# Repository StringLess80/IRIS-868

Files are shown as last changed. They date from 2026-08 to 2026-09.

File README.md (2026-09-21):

<div align="center">

# 📡 IRIS-868

**Custom embedded RF platform for the 868 MHz ISM band**

IRIS-868 is a custom embedded RF platform based on the STM32F303RET6 microcontroller and an Ebyte E22-900M22S (Semtech SX1262) sub-GHz LoRa module, designed for 868 MHz ISM-band wireless communication and data logging.

<br/>














<br/>

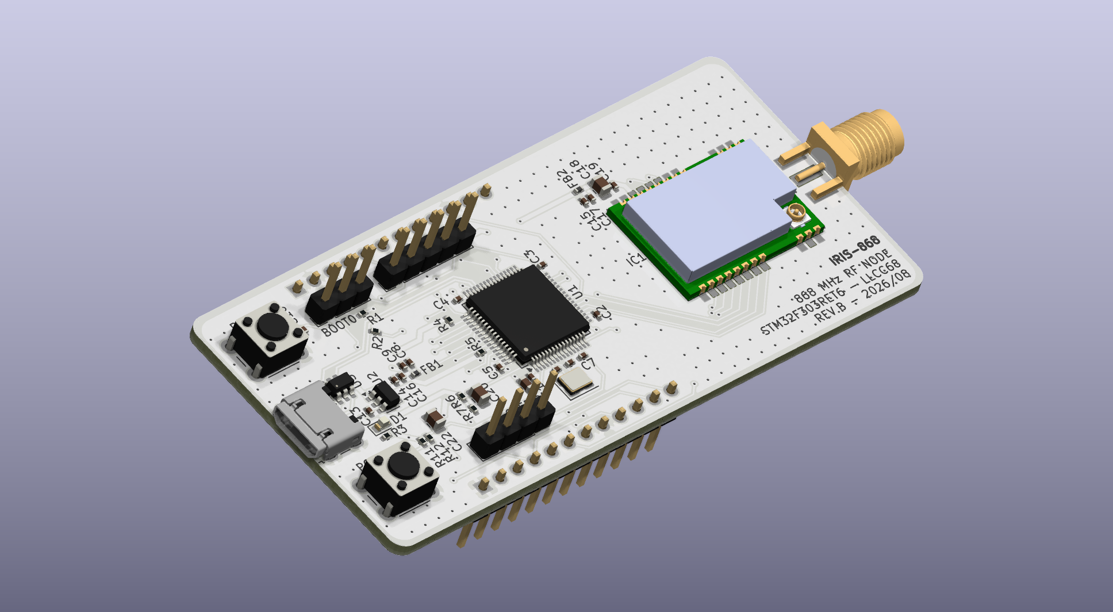
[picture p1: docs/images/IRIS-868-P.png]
IRIS-868


</div>

---

## ⚡ At a glance

|  |  |
|---|---|
| 🧠 **MCU** | STM32F303RET6 · Cortex-M4F @ 72 MHz · 512 KB flash · 64 + 16 KB RAM |
| 📻 **Radio** | Ebyte E22-900M22S · SX1262 · +22 dBm · LoRa / (G)FSK |
| 💾 **Storage** | Winbond W25Q128JV · 128 Mbit (16 MiB) SPI NOR flash for data logging |
| 🔌 **Power** | USB micro-B → AP2112K-3.3 LDO, filtered analog and RF rails, VBUS voltage monitoring on the ADC |
| 🧩 **Expansion** | 2 × 12-pin edge headers · I²C header for 128×64 OLED · 5-pin SWD with NRST · BOOT0 jumper · user button |
| 📐 **Board** | 2-layer FR4 · 78.8 × 36.6 mm · white mask, black silk · components on both sides |
| 🛠️ **Tooling** | KiCad 9, project-local libraries, no global config needed |

> [!WARNING]
> **Revision B is design-complete but has not been bring-up tested.** Fabrication files are released as-is. No firmware is included in this repository yet. See [Known limitations](#-known-limitations) before ordering.

## 📑 Table of contents

- [What's new in revision B](#-whats-new-in-revision-b)
- [Gallery](#%EF%B8%8F-gallery)
- [System architecture](#%EF%B8%8F-system-architecture)
- [Repository layout](#-repository-layout)
- [Hardware overview](#-hardware-overview)
- [Pin assignment](#-pin-assignment)
- [Board specification](#-board-specification)
- [Bill of materials](#-bill-of-materials)
- [Getting started](#-getting-started)
- [Known limitations](#-known-limitations)

## 🆕 What's new in revision B

| Area | Revision A | Revision B |
|---|---|---|
| **Expansion** | Most GPIOs unrouted | Two 1×12 edge headers (J5, J7) bring out power, reset, BOOT0, USART1 and 13 GPIOs |
| **Debug** | 4-pin SWD, no NRST | 5-pin SWD **with NRST** — "connect under reset" now works |
| **Storage** | — | 16 MiB W25Q128JV SPI flash on SPI3 (bottom side) |
| **User input** | Reset button only | Additional user button on **PC13** with RC debounce |
| **Monitoring** | — | VBUS divider (47 kΩ / 15 kΩ) on **PC0** for USB voltage measurement |
| **USB** | D+ pull-up fixed to +3.3 V | D+ pull-up driven by **PB8** — firmware-controlled attach/detach |
| **Radio** | E220-900M22S (LLCC68) | E22-900M22S (SX1262), same pinout and pin assignment |
| **Board** | 74.2 × 32.0 mm, single-sided assembly | 78.8 × 36.6 mm, bottom-side SMD parts and headers |

## 🖼️ Gallery

<div align="center">

| Front | Back |
|:---:|:---:|
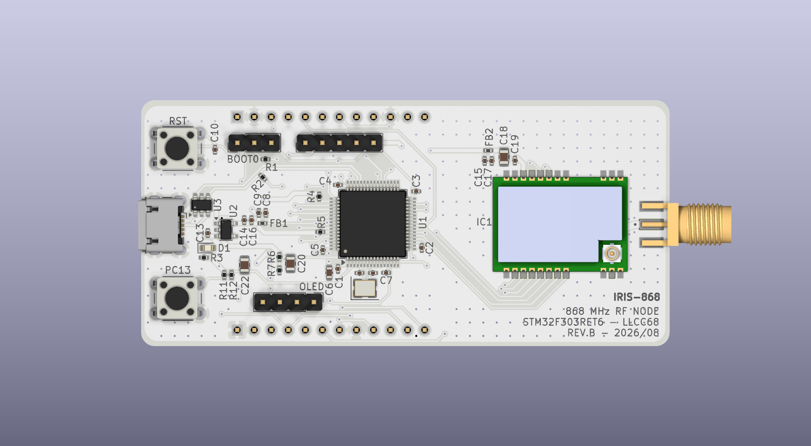
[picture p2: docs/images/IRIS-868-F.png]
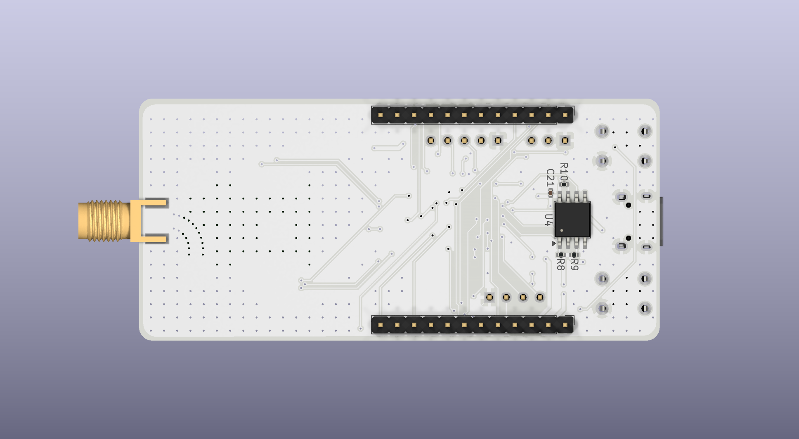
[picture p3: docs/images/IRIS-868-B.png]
|  |  |

</div>

📄 Full schematic: [`docs/schematics/IRIS-868.pdf`](docs/schematics/IRIS-868.pdf)

## 🏗️ System architecture

```mermaid
flowchart LR
    USB["USB micro-B<br/>J2"] -->|VBUS 5 V| LDO["AP2112K-3.3<br/>600 mA LDO"]
    USB -.->|"D+ / D-"| ESD["USBLC6-2SC6<br/>ESD"]
    ESD -.-> MCU
    USB -->|"VBUS ÷ 4.13"| VMON["V_MON<br/>PC0 / ADC"]
    VMON --> MCU

    LDO --> RAIL(("3.3 V"))
    RAIL -->|"FB1 120 Ω"| VDDA["+3.3VA"]
    RAIL -->|"FB2 120 Ω"| VRF["VRF"]
    RAIL --> MCU
    VDDA --> MCU
    VRF --> MOD

    MCU["STM32F303RET6<br/>Cortex-M4F @ 72 MHz"]
    MCU <-->|"SPI1 · NSS · BUSY · DIO1 · NRST"| MOD["E22-900M22S<br/>SX1262 · +22 dBm"]
    MCU -->|"RXEN / TXEN"| MOD
    MOD -->|ANT| SMA["SMA edge<br/>J6"]

    MCU <-->|"SPI3 · CS"| FLASH["W25Q128JV<br/>16 MiB flash"]
    MCU <-->|"I²C1"| OLED["128×64 OLED<br/>header"]
    MCU <-->|"SWD + NRST"| DBG["ST-Link<br/>J3"]
    MCU <-->|"GPIO · USART1"| HDR["Edge headers<br/>J5 / J7"]
    BTN["User button<br/>PC13"] --> MCU
    MCU -.->|BOOT0| JMP["Boot jumper"]

    style MCU fill:#03234B,color:#fff
    style MOD fill:#2ea44f,color:#fff
    style FLASH fill:#8e44ad,color:#fff
    style RAIL fill:#f39c12,color:#fff
```

## 📁 Repository layout

```
IRIS-868/
├── hardware/
│   ├── kicad/                 KiCad 9 project (schematic, PCB, design rules)
│   │   └── libs/              Project-local symbols, footprints, 3D models
│   └── gerbers/rev.B/         Gerber X2 + Excellon drill files
└── docs/
    ├── schematics/            Schematic PDF
    ├── images/                Board renders
    └── datasheets/            Component reference documents
```

The schematic is hierarchical: the root sheet (`IRIS-868.kicad_sch`) holds the MCU, crystal, reset, buttons, VBUS monitor, flash and headers, with sub-sheets for power and USB (`pwr.kicad_sch`), the radio (`rf.kicad_sch`) and connectors (`interfaces.kicad_sch`).

## 🔧 Hardware overview

### Power

USB VBUS feeds an **AP2112K-3.3** LDO (SOT-23-5, 600 mA) that generates the single 3.3 V system rail. Three domains branch from it:

| Rail | Source | Decoupling | Purpose |
|---|---|---|---|
| `+3.3V` | LDO output | 10 µF + 7 × 100 nF + 2 × 1 µF | MCU digital, I/O, flash, headers |
| `+3.3VA` | via FB1 (120 Ω ferrite) | 1 µF + 10 nF | STM32 VDDA / analog reference |
| `VRF` | via FB2 (120 Ω ferrite) | 22 µF + 1 µF + 2 × 100 nF | RF module supply |

The ferrite beads isolate the analog and RF domains from digital switching noise on the main rail. The 22 µF bulk capacitor on `VRF` supplies the current burst drawn by the module during transmission.

VBUS and +3.3 V are both available on header J5, so the board can supply a small carrier or add-on board.

### VBUS monitoring

A 47 kΩ / 15 kΩ divider (R6 / R7) scales VBUS onto `V_MON` (**PC0**, ADC12_IN6), filtered by C20 (100 nF). The divider ratio is 15 / 62, so 5.0 V on VBUS reads as about 1.21 V, and firmware recovers VBUS as `V_MON × 4.133`. The divider draws roughly 80 µA from VBUS, and its ~11 kΩ source impedance combined with C20 gives a stable input for the ADC sample-and-hold.

### RF chain

The E22-900M22S connects to the MCU over SPI1 plus four control lines. `RXEN` and `TXEN` drive the module's internal RF switch and must be managed by firmware around every transmit/receive transition. The antenna net (`ANT`) runs from the module's stamp-hole RF pad to the SMA edge connector as a short (≈ 4.6 mm), 1.0 mm-wide ground-referenced coplanar trace on F.Cu; a project-specific design rule enforces a 0.15 mm gap to the surrounding copper pour along this net.

### Data-logging flash

A **Winbond W25Q128JVSIQ** (SOIC-8, 208 mil) on the bottom side provides 16 MiB of non-volatile storage on **SPI3** (PC10 / PC11 / PC12) with chip select on **PD2**. The CS line has a 10 kΩ pull-up (R8) so the flash stays deselected while the MCU is in reset. `/WP` and `/HOLD` are tied high through R9 and R10, so the device operates in standard single-bit SPI mode; dual/quad I/O is not available on this revision. C21 decouples the flash locally.

### User input and reset

| Button | Net | Circuit |
|---|---|---|
| **RST** | NRST (pin 7) | Pulls NRST low, 100 nF (C10) on the line. NRST is also on the SWD header and J5 |
| **PC13** | PC13 (pin 2) | Active-low. 10 kΩ pull-up (R11), 10 kΩ series (R12), 100 nF (C22) to GND — about 1 ms fall / 2 ms rise debounce |

### USB

The USB D+ 1.5 kΩ pull-up (R2) is connected to **PB8** rather than to +3.3 V. Firmware must drive PB8 high to signal device attach to the host, and can drive it low to force a clean disconnect/re-enumeration without unplugging the cable. See [Known limitations](#-known-limitations) for the effect on the ROM DFU bootloader.

### Interfaces

| Connector | Type | Pinout |
|---|---|---|
| **J2** USB | micro-B | USB FS device on PA11/PA12, D+ pull-up switched by PB8, ESD-protected |
| **J3** SWD | 1×5 @ 2.54 mm | `GND` · `NRST` · `SWCLK` · `SWDIO` · `+3.3V` |
| **BOOT0** | 1×3 @ 2.54 mm | `GND` · `BOOT0` · `+3.3V` — jumper 1–2 = flash, 2–3 = bootloader |
| **OLED** | 1×4 @ 2.54 mm | `GND` · `+3.3V` · `SCL` · `SDA` (1.5 kΩ pull-ups on board) |
| **J5** | 1×12 @ 2.54 mm, bottom-mounted | Power, reset, BOOT0, USART1, GPIO — see below |
| **J7** | 1×12 @ 2.54 mm, bottom-mounted | GPIO — see below |
| **J6** SMA | edge-mount | Antenna |

### Edge headers

J5 and J7 run along the long edges of the board with a row-to-row spacing of 31.75 mm (1.25 in). The header bodies are mounted on the bottom side, so the board can be plugged into a carrier with the components facing up. Pin 1 of each header is at the USB end.

| Pin | **J5** | **J7** |
|:---:|---|---|
| 1 | `GND` | `PB9` |
| 2 | `+3.3V` | `GND` |
| 3 | `VBUS` (5 V) | `PB0` |
| 4 | `NRST` | `PB1` |
| 5 | `BOOT0` | `PC4` |
| 6 | `PA9` (USART1_TX) | `PC5` |
| 7 | `PA10` (USART1_RX) | `PC6` |
| 8 | `GND` | `PC7` |
| 9 | `PB4` | `PC8` |
| 10 | `PB5` | `GND` |
| 11 | `PB6` | not connected |
| 12 | `PB8` ⚠️ USB D+ pull-up | not connected |

## 📌 Pin assignment

### STM32F303RET6 ↔ E22-900M22S

| STM32 pin | Signal | Module pin | Direction | Function |
|---|---|---|:---:|---|
| `PA5` | SPI1_SCK | 18 (SCK) | → | SPI clock |
| `PA6` | SPI1_MISO | 16 (MISO) | ← | SPI data out |
| `PA7` | SPI1_MOSI | 17 (MOSI) | → | SPI data in |
| `PA4` | NSS | 19 (NSS) | → | Chip select, active low |
| `PA3` | NRST | 15 (NRST) | → | Module reset, active low |
| `PA2` | BUSY | 14 (BUSY) | ← | Transceiver busy status |
| `PA8` | DIO1 | 13 (DIO1) | ← | Primary interrupt line |
| `PB10` | RXEN | 6 (RXEN) | → | RF switch, receive enable |
| `PB11` | TXEN | 7 (TXEN) | → | RF switch, transmit enable |

Module pin 8 (DIO2) is left unconnected in revision B.

### STM32F303RET6 ↔ W25Q128JV

| STM32 pin | Signal | Flash pin | Direction |
|---|---|---|:---:|
| `PC10` | SPI3_SCK | 6 (CLK) | → |
| `PC11` | SPI3_MISO | 2 (DO) | ← |
| `PC12` | SPI3_MOSI | 5 (DI) | → |
| `PD2` | FLASH_CS | 1 (/CS) | → |

<details>
<summary><b>Other pin assignments</b></summary>

<br/>

| STM32 pin | Function |
|---|---|
| `PA11` / `PA12` | USB D− / D+ |
| `PB8` | USB D+ pull-up control (also on J5 pin 12) |
| `PA13` / `PA14` | SWDIO / SWCLK |
| `PA15` | I²C1 SCL (AF4) |
| `PB7` | I²C1 SDA (AF4) |
| `PC0` | V_MON — VBUS voltage divider (ADC) |
| `PC13` | User button, active low |
| `PF0` / `PF1` | 16 MHz crystal (OSC_IN / OSC_OUT) |
| `NRST` (pin 7) | Reset button + 100 nF, SWD header, J5 |
| `BOOT0` (pin 60) | BOOT0 jumper via 10 kΩ, J5 (direct) |
| `PA9`, `PA10`, `PB4`–`PB6` | J5 |
| `PB0`, `PB1`, `PB9`, `PC4`–`PC8` | J7 |

The remaining GPIOs — `PA0`, `PA1`, `PB2`, `PB3`, `PB12`–`PB15`, `PC1`–`PC3`, `PC9`, `PC14`, `PC15` — are **not routed** in revision B.

</details>

## 📐 Board specification

| Parameter | Value |
|---|---|
| Dimensions | 78.8 × 36.6 mm, 2 mm corner radius |
| Layers | 2 (F.Cu / B.Cu), GND pour on both |
| Stackup | 1.6 mm FR4, 35 µm copper, εr 4.5 |
| Surface finish | HASL |
| Vias | 369 |
| Assembly | Double-sided (U4, R8–R10, C21 and header bodies on the bottom) |
| Special rules | 0.15 mm clearance on the `ANT` coplanar feedline |

## 🧾 Bill of materials

<details>
<summary><b>Full BOM — 52 components</b></summary>

<br/>

| Ref | Qty | Value | Package | Notes |
|---|:---:|---|---|---|
| U1 | 1 | STM32F303RET6 | LQFP-64 | 0.5 mm pitch |
| U2 | 1 | AP2112K-3.3 | SOT-23-5 | 600 mA LDO |
| U3 | 1 | USBLC6-2SC6 | SOT-23-6 | USB ESD protection |
| U4 | 1 | W25Q128JVSIQ | SOIC-8 5.3 × 5.3 mm | 128 Mbit SPI flash, **bottom side** |
| IC1 | 1 | E22-900M22S | Ebyte SMD module | SX1262, +22 dBm |
| Y1 | 1 | 16 MHz | 3225-4pin | ≤20 ppm recommended |
| C1–C5, C10, C16, C17, C19, C21 | 10 | 100 nF | 0402 | 16 V X7R — C21 on bottom side |
| C20, C22 | 2 | 100 nF | 0805 | 16 V X7R — V_MON filter, PC13 debounce |
| C8, C9, C14, C15 | 4 | 1 µF | 0402 | 16 V X5R/X7R |
| C13 | 1 | 1 µF | 0402 | **25 V** — sits on the 5 V VBUS rail |
| C6 | 1 | 10 µF | 0603 | 16 V X5R |
| C18 | 1 | 22 µF | 0805 | 16 V X5R, RF bulk |
| C7 | 1 | 10 nF | 0402 | 16 V X7R, VDDA filter |
| C11, C12 | 2 | 12 pF | 0402 | **50 V C0G/NP0 ±5%**, crystal load |
| R1 | 1 | 10 kΩ | 0402 | BOOT0 series |
| R2 | 1 | 1.5 kΩ | 0402 | USB D+ pull-up (to PB8) |
| R3 | 1 | 1.5 kΩ | 0402 | Power LED series |
| R4, R5 | 2 | 1.5 kΩ | 0402 | I²C pull-ups |
| R6 | 1 | 47 kΩ | 0402 | VBUS divider, top — 1% recommended |
| R7 | 1 | 15 kΩ | 0402 | VBUS divider, bottom — 1% recommended |
| R8, R9, R10 | 3 | 10 kΩ | 0402 | Flash /CS, /WP, /HOLD pull-ups, **bottom side** |
| R11, R12 | 2 | 10 kΩ | 0402 | PC13 button pull-up / series |
| FB1, FB2 | 2 | 120 Ω @ 100 MHz | 0402 | Analog / RF rail filtering |
| D1 | 1 | Red LED | 0603 | Power indicator |
| RST, PC13 | 2 | Tactile switch | 6 mm THT | 4-pin, 4.5 × 6.5 mm |
| BOOT0 | 1 | Pin header 1×3 | 2.54 mm | BOOT0 select |
| J2 | 1 | USB micro-B | Würth 629105150521 | |
| J3 | 1 | Pin header 1×5 | 2.54 mm | SWD + NRST |
| OLED | 1 | Pin header 1×4 | 2.54 mm | I²C / OLED |
| J5, J7 | 2 | Pin header 1×12 | 2.54 mm | Edge headers, **bottom side** |
| J6 | 1 | SMA edge-mount | RF Solutions CON-SMA-EDGE-S | |

</details>

> [!TIP]
> Capacitor voltage ratings account for MLCC **DC bias derating** — class II ceramics lose a large fraction of their nominal capacitance near their rated voltage, so ratings are specified at roughly 4–5× the working voltage. Don't forget to order a **2.54 mm jumper shunt** for the BOOT0 header; it isn't part of the PCB BOM.

## 🚀 Getting started

<details open>
<summary><b>1 · Fabricate the board</b></summary>

<br/>

Fabrication files for revision B are in [`hardware/gerbers/rev.B/`](hardware/gerbers/rev.B/), in Gerber X2 format with Excellon drill files. They can be uploaded directly to most fabricators.

- Process: standard 2-layer, 1.6 mm FR4, HASL or ENIG
- No controlled impedance is specified
- Revision B has SMD parts on **both sides**. If using assembly service, request double-sided assembly or have the bottom-side parts (U4, R8–R10, C21) left unpopulated and fit them by hand
- Suggested hand-assembly order: bottom-side SMD parts first, then the STM32 (drag solder, then inspect with flux and a loupe), then the remaining ICs, then passives, then the module, then through-hole parts last — edge headers J5/J7 go in from the bottom

</details>

<details>
<summary><b>2 · Open the design</b></summary>

<br/>

The project requires **KiCad 9** or later. Symbols, footprints and 3D models for the non-standard parts (E22 module, SMA edge connector) live under `hardware/kicad/libs/` and are referenced with project-relative paths, so the project opens without any global library configuration.

```bash
git clone -b v2 https://github.com/StringLess80/IRIS-868.git
cd IRIS-868
kicad hardware/kicad/IRIS-868.kicad_pro
```

</details>

<details>
<summary><b>3 · Program it</b></summary>

<br/>

**Via SWD (recommended)** — connect an ST-Link or any CMSIS-DAP probe to J3, including the NRST line. Because NRST is on the header, "connect under reset" works, so a board with firmware that disables SWD or enters low-power mode early can still be recovered from the debugger.

```bash
st-flash --reset write firmware.bin 0x08000000
```

**Via UART bootloader** — connect a 3.3 V USB-serial adapter to J5 (`PA9` = MCU TX, `PA10` = MCU RX, `GND`), move the BOOT0 jumper to pins 2–3 and reset:

```bash
stm32flash -w firmware.bin -v -g 0x0 /dev/ttyUSB0
```

**Via USB DFU** — the ROM bootloader does not drive PB8, so the D+ pull-up is inactive and the host will not see the device (see [Known limitations](#-known-limitations)). Tie J5 pin 12 (`PB8`) to J5 pin 2 (`+3.3V`) for the duration of the DFU session, move the BOOT0 jumper to pins 2–3, reset, then:

```bash
dfu-util -a 0 -s 0x08000000:leave -D firmware.bin
```

> [!CAUTION]
> Remove the PB8 link before running application firmware — if firmware drives PB8 low while it is tied to +3.3 V, the pin is shorted.

Move the jumper back to pins 1–2 and reset to run from flash.

</details>

## 🐛 Known limitations

Revision B has the following documented issues and constraints:

| # | Issue | Impact | Workaround |
|:---:|---|---|---|
| 1 | **BOOT0 needs a jumper** — R1 is wired in series between BOOT0 and the jumper header, not as a fixed pull-down, so BOOT0 floats with no shunt fitted (unless driven through J5 pin 5) | Boot mode is undefined after reset | Always keep a jumper on the BOOT0 header, pins 1–2 for normal operation |
| 2 | **USB D+ pull-up depends on PB8** | ROM USB DFU bootloader cannot enumerate; PB8 on J5 is effectively reserved for USB | Use SWD or the UART bootloader, or link PB8 to +3.3 V during DFU. Don't load J5 pin 12 when USB is used |
| 3 | **Flash wired for single SPI only** — /WP and /HOLD are pulled up, not routed to the MCU | No dual/quad I/O | None needed for most logging workloads |
| 4 | **Some GPIOs still unrouted** — `PA0`, `PA1`, `PB2`, `PB3`, `PB12`–`PB15`, `PC1`–`PC3`, `PC9`, `PC14`, `PC15`; J7 pins 11–12 are unused | Fewer I/Os than the MCU offers | Rework |

Resolved from revision A: NRST is now on the SWD header, and most previously unrouted GPIOs are available on J5 / J7.

<div align="center">
<br/>

Made with [KiCad](https://www.kicad.org/) 🛠️

</div>

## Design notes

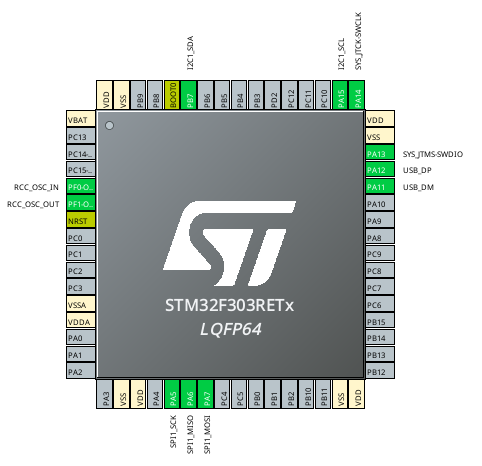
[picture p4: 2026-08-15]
docs/misc/Screenshot From 2026-08-11 23-41-10.png

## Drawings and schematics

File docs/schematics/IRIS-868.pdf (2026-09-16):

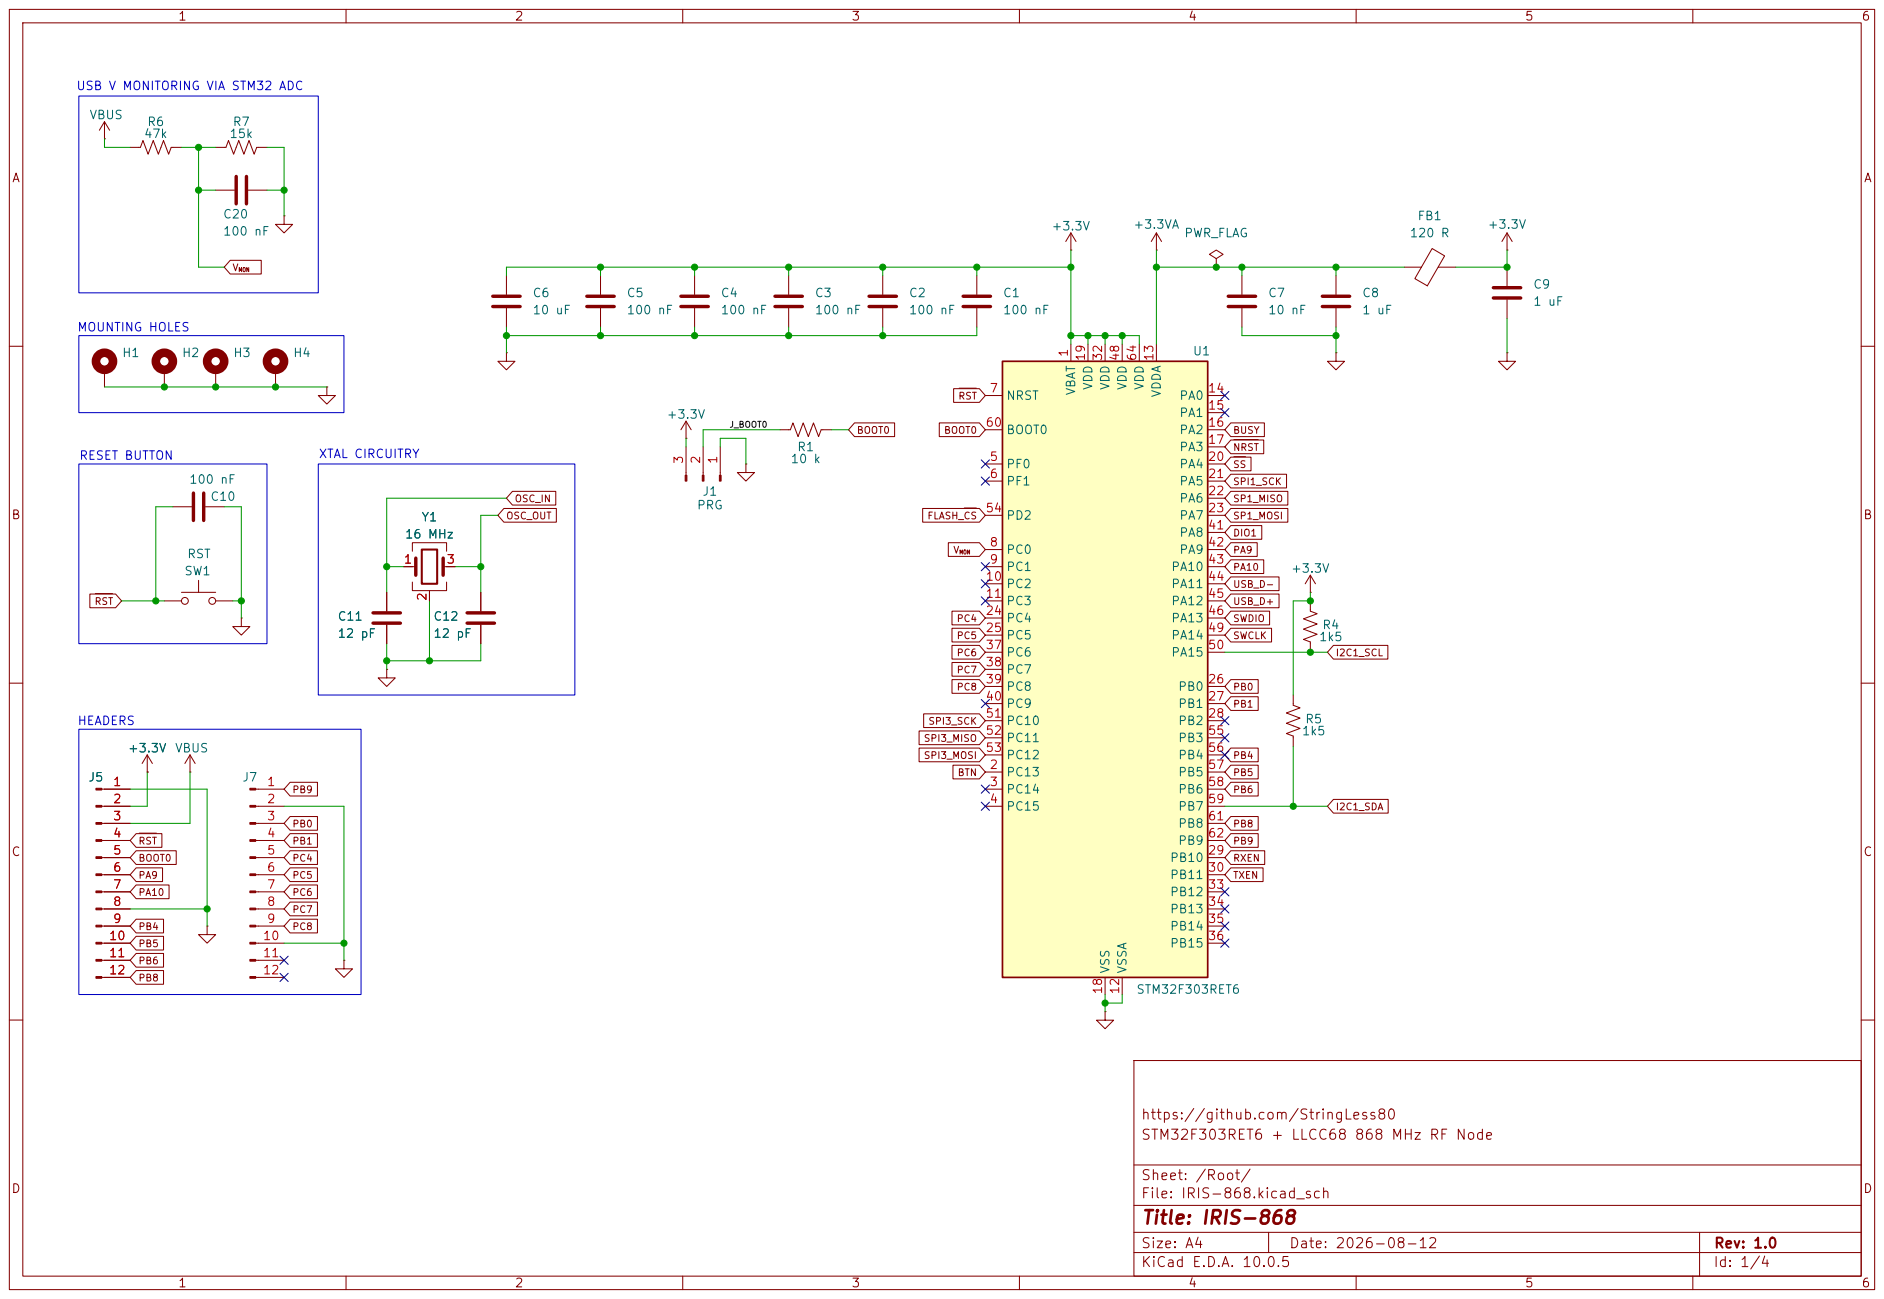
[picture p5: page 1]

BOOT0 J_BOOT0 HEADERS RESET BUTTON MOUNTING HOLES USB V MONITORING VIA STM32 ADC

Size: A4 | Rev: 1.0
KiCad E.D.A. 10.0.5 | Id: 1/4

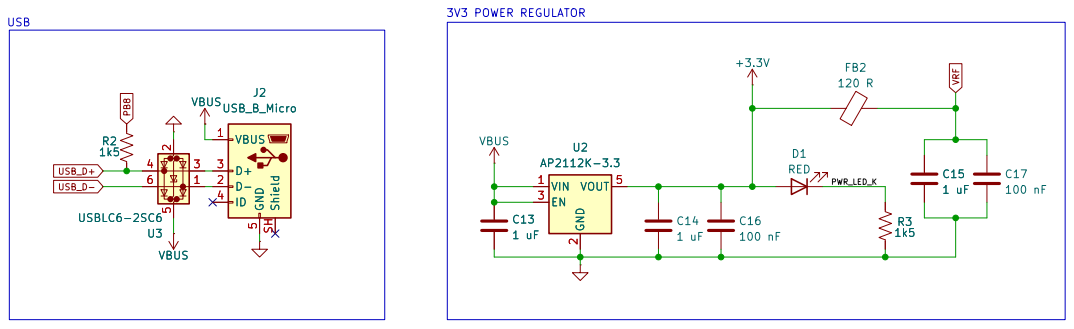
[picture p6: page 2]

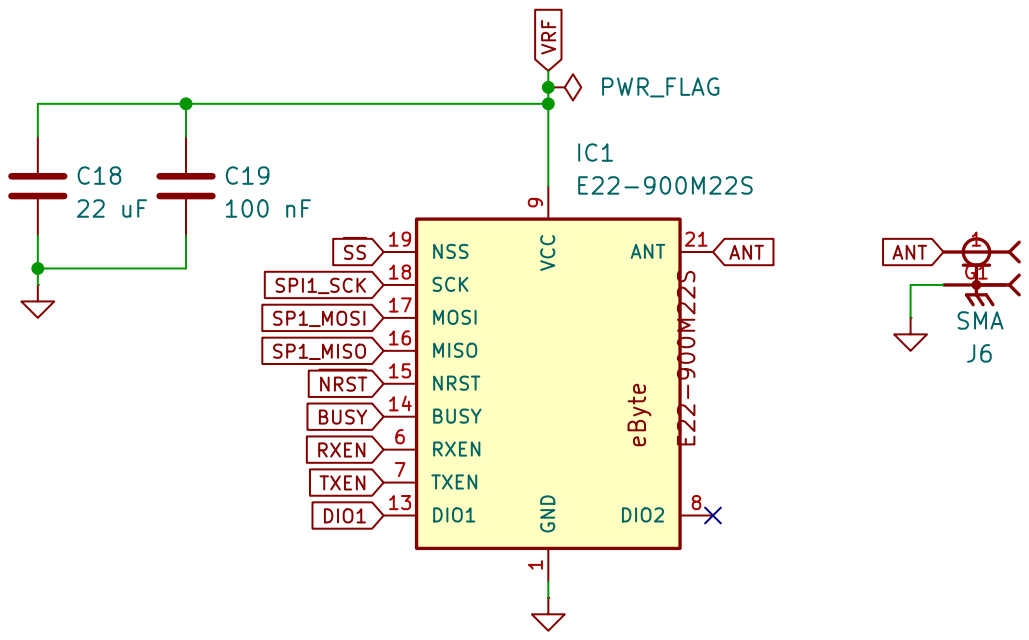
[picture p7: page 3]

9 DIO1 13 BUSY 14 NRST 15 MISO 16 MOSI 17

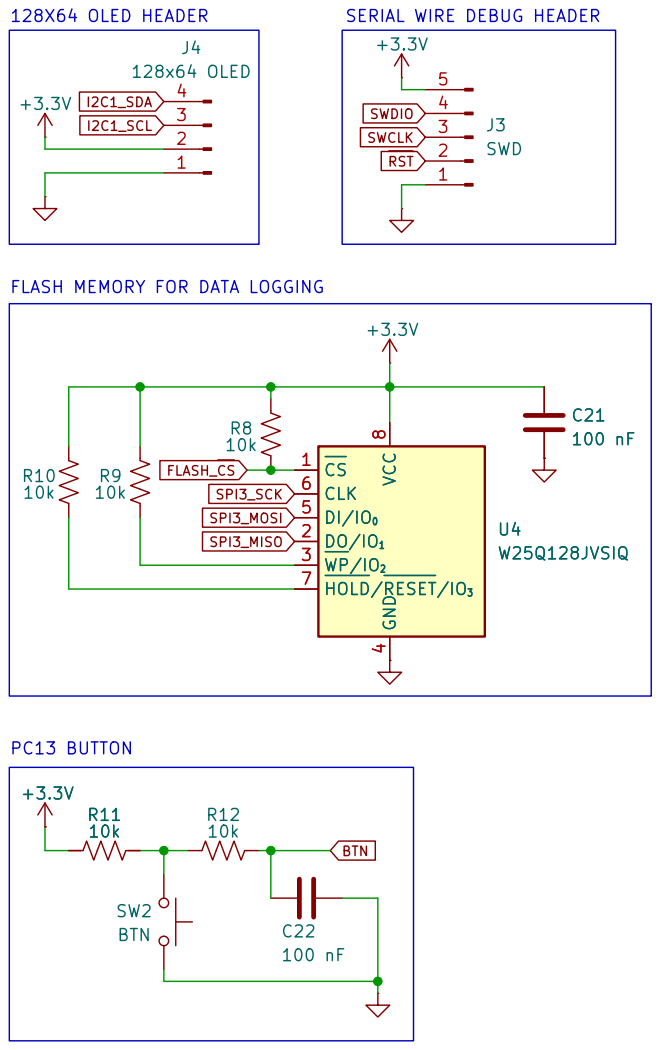
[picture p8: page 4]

FLASH MEMORY FOR DATA LOGGING

4 DI/IO0 5 CLK 6 HOLD/RESET/IO3 7 VCC

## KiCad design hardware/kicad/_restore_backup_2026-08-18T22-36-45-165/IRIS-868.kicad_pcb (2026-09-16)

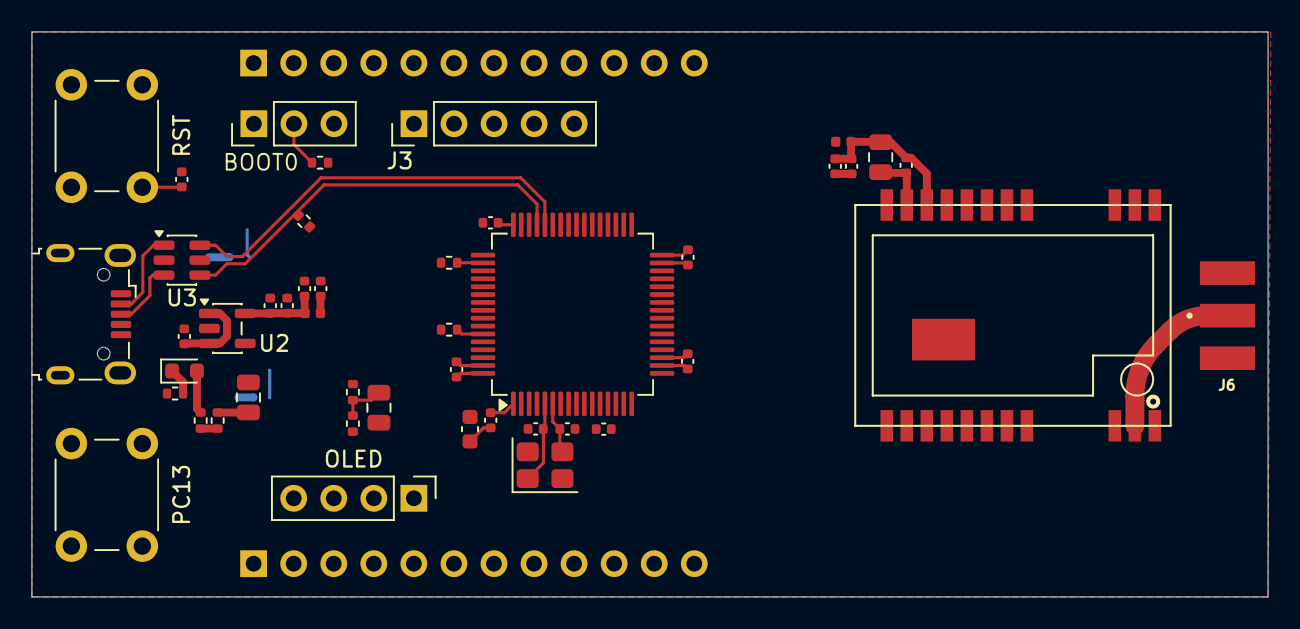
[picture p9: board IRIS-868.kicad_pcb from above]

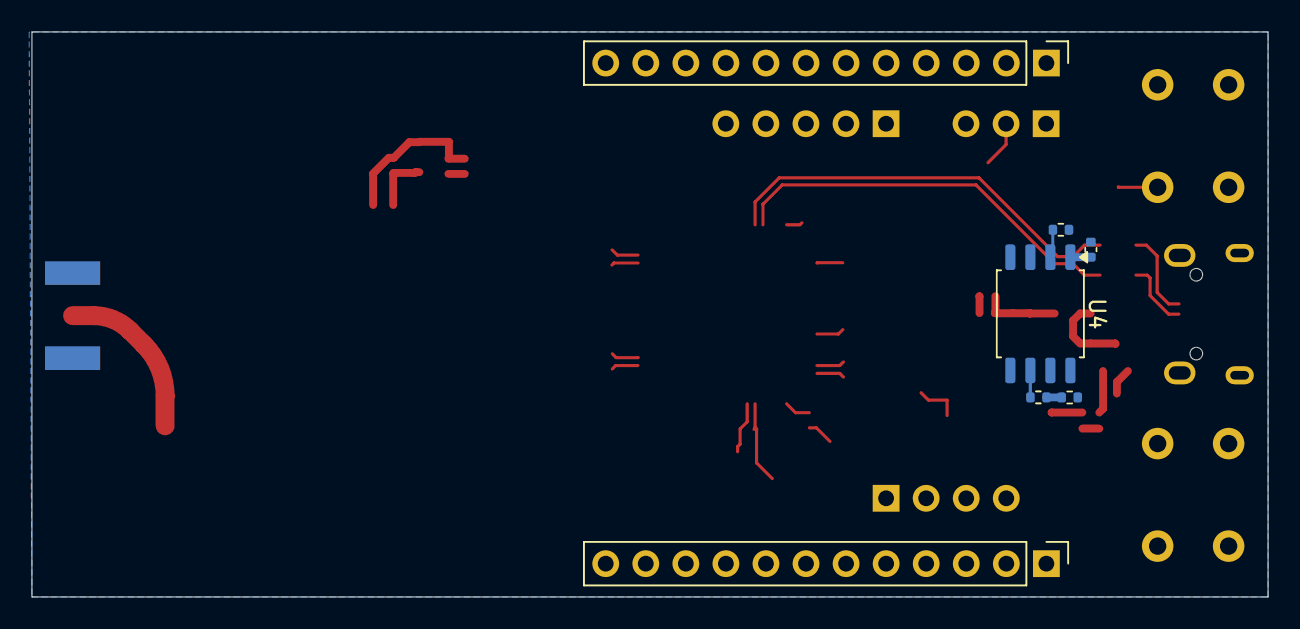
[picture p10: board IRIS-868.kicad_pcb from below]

Board: 2 copper layers, 78.4 x 35.8 mm, 52 parts (7 on the bottom side), 52 nets.

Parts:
BOOT0: PRG; PinHeader_1x03_P2.54mm_Vertical
C1, C2, C3, C4, C5, C10, C16, C17, C19, C21: 100 nF; C_0402_1005Metric
C6: 10 uF; C_0603_1608Metric
C7: 10 nF; C_0402_1005Metric
C8, C9, C13, C14, C15: 1 uF; C_0402_1005Metric
C11, C12: 12 pF; C_0402_1005Metric
C18: 22 uF; C_0805_2012Metric
C20, C22: 100 nF; C_0805_2012Metric
D1: RED; LED_0603_1608Metric
FB1, FB2: 120 R; L_0402_1005Metric
IC1: E22-900M22S
J2: USB_B_Micro; USB_Micro-B_Wuerth_629105150521
J3: SWD; PinHeader_1x05_P2.54mm_Vertical
J5, J7: Conn_01x12_Pin; PinHeader_1x12_P2.54mm_Vertical
J6: SMA; RFSOLUTIONS_CON-SMA-EDGE-S
OLED: 128x64 OLED; PinHeader_1x04_P2.54mm_Vertical
PC13: BTN; SW_PUSH_6mm
R1: 10 k; R_0402_1005Metric
R2, R3, R4, R5: 1k5; R_0402_1005Metric
R6: 47k; R_0402_1005Metric
R7: 15k; R_0402_1005Metric
R8, R9, R10, R11, R12: 10k; R_0402_1005Metric
RST: RST; SW_PUSH_6mm
U1: STM32F303RET6; LQFP-64_10x10mm_P0.5mm
U2: AP2112K-3.3; SOT-23-5
U3: USBLC6-2SC6; SOT-23-6
U4: W25Q128JVSIQ; SOIC-8_5.3x5.3mm_P1.27mm
Y1: 16 MHz; Crystal_SMD_3225-4Pin_3.2x2.5mm

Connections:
+3.3V: BOOT0.3, C1.1, C2.1, C3.1, C4.1, C5.1, C6.1, C9.1, C14.1, C16.1, C21.1, D1.2 (A), FB1.2, FB2.1, J3.5, J5.2, OLED.2, R4.2, R5.2, R8.1, R9.1, R10.1, R11.2, U1.1 (VBAT), U1.19 (VDD), U1.32 (VDD), U1.48 (VDD), U1.64 (VDD), U2.5 (VOUT), U4.8 (VCC)
+3.3VA: C7.1, C8.1, FB1.1, U1.13 (VDDA)
/PWR-USB/PWR_LED_K: D1.1 (K), R3.2
/Root/J_BOOT0: BOOT0.2, R1.1
ANT: IC1.21 (ANT), J6.1
BOOT0: J5.5, R1.2, U1.60 (BOOT0)
BTN: C22.1, R12.1, U1.2 (PC13)
BUSY: IC1.14 (BUSY), U1.16 (PA2)
DIO1: IC1.13 (DIO1), U1.41 (PA8)
ESD+: J2.3 (D+), U3.3 (I/O2)
ESD-: J2.2 (D-), U3.1 (I/O1)
FLASH_~CS: R8.2, U1.54 (PD2), U4.1 (~CS)
GND: BOOT0.1, C1.2, C2.2, C3.2, C4.2, C5.2, C6.2, C7.2, C8.2, C9.2, C10.2, C11.2, C12.2, C13.2, C14.2, C15.2, C16.2, C17.2, C18.2, C19.2, C20.2, C21.2, C22.2, IC1.1 (GND), IC1.2 (GND), IC1.3 (GND), IC1.4 (GND), IC1.5 (GND), IC1.10 (GND), IC1.11 (GND), IC1.12 (GND), IC1.20 (GND), IC1.22 (GND), J2.5 (GND), J3.1, J5.1, J5.8, J6.G1, J6.G2, J6.G3, J6.G4, J7.2, J7.10, OLED.1, PC13.2, R3.1, R7.1, RST.2, U1.12 (VSSA), U1.18 (VSS), U1.31 (VSS), U1.47 (VSS), U1.63 (VSS), U2.2 (GND), U3.2 (GND), U4.4 (GND), Y1.2 (G), Y1.4 (G)
I2C1_SCL: OLED.3, R4.1, U1.50 (PA15)
I2C1_SDA: OLED.4, R5.1, U1.59 (PB7)
unnamed: PC13.1, R11.1, R12.2
unnamed: R10.2, U4.7 (~HOLD/~RESET/IO_{3})
unnamed: R9.2, U4.3 (~WP/IO_{2})
OSC_IN: C11.1, U1.5 (PF0), Y1.1
OSC_OUT: C12.1, U1.6 (PF1), Y1.3
PA9: J5.6, U1.42 (PA9)
PA10: J5.7, U1.43 (PA10)
PB0: J7.3, U1.26 (PB0)
PB1: J7.4, U1.27 (PB1)
PB4: J5.9, U1.56 (PB4)
PB5: J5.10, U1.57 (PB5)
PB6: J5.11, U1.58 (PB6)
PB8: J5.12, R2.2, U1.61 (PB8)
PB9: J7.1, U1.62 (PB9)
PC4: J7.5, U1.24 (PC4)
PC5: J7.6, U1.25 (PC5)
PC6: J7.7, U1.37 (PC6)
PC7: J7.8, U1.38 (PC7)
PC8: J7.9, U1.39 (PC8)
RXEN: IC1.6 (RXEN), U1.29 (PB10)
SP1_MISO: IC1.16 (MISO), U1.22 (PA6)
SP1_MOSI: IC1.17 (MOSI), U1.23 (PA7)
SPI1_SCK: IC1.18 (SCK), U1.21 (PA5)
SPI3_MISO: U1.52 (PC11), U4.2 (DO/IO_{1})
SPI3_MOSI: U1.53 (PC12), U4.5 (DI/IO_{0})
SPI3_SCK: U1.51 (PC10), U4.6 (CLK)
SWCLK: J3.3, U1.49 (PA14)
SWDIO: J3.4, U1.46 (PA13)
TXEN: IC1.7 (TXEN), U1.30 (PB11)
USB_D+: R2.1, U1.45 (PA12), U3.4 (I/O2)
USB_D-: U1.44 (PA11), U3.6 (I/O1)
VBUS: C13.1, J2.1 (VBUS), J5.3, R6.2, U2.1 (VIN), U2.3 (EN), U3.5 (VBUS)
VRF: C15.1, C17.1, C18.1, C19.1, FB2.2, IC1.9 (VCC)
V_{MON}: C20.1, R6.1, R7.2, U1.8 (PC0)
~NRST: IC1.15 (NRST), U1.17 (PA3)
~RST: C10.1, J3.2, J5.4, RST.1, U1.7 (NRST)
~SS: IC1.19 (NSS), U1.20 (PA4)

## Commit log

2026-08-15 Reloaded gerber
    [IRIS-868-B_Cu.gbl, IRIS-868-B_Mask.gbs, IRIS-868-B_Paste.gbp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]
2026-09-16 rev 2
    [IRIS-868-B_Cu.gbl, IRIS-868-B_Mask.gbs, IRIS-868-B_Paste.gbp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]
2026-09-16 REV 2 BOM
